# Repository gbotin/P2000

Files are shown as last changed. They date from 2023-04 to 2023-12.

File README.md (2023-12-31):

Infos :
Stepper : 28byj-48

http://suncalc.net/#/50.6244,2.6875,9/2023.12.01/15:34

FIFO readings
https://github.com/rlogiacco/CircularBuffer

https://github.com/adafruit/RTClib

### TODO :
- update stepper lib to accelstepper
- buy rtc module
- homing step motor - buy homing switch

### Utils :
- Read current time : echo "time_print" > /dev/tty.usbserial-1230
- Send current time : echo "time_set $(date +%s)" > /dev/tty.usbserial-1440
- Reset EEPROM : echo 'eeprom_reset' > /dev/tty.usbserial-1230

### Infos :
- Stepper : 28byj-48

### FIFO readings info
- https://github.com/rlogiacco/CircularBuffer

### Libs 

- https://github.com/PaulStoffregen/Time
- http://github.com/JChristensen/Timezone
- https://github.com/arduino-libraries/Stepper
- https://github.com/dmkishi/Dusk2Dawn

### Power Consumption

Mode SET idle : 0.0358V
Motor running 

sleep 0.146

max 0.2620

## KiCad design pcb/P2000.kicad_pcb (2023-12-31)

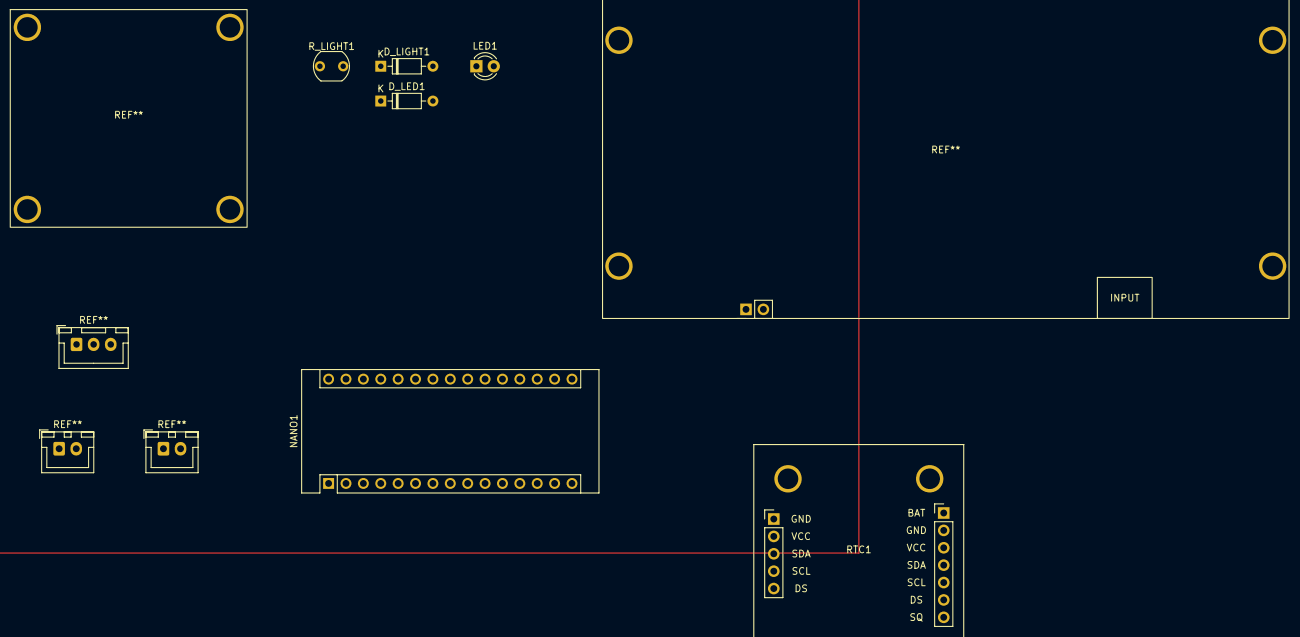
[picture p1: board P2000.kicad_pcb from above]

Board: 2 copper layers, 6 parts (0 on the bottom side), 8 nets, no tracks yet.

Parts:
D_LED1: 1N4148; D_DO-35_SOD27_P7.62mm_Horizontal
D_LIGHT1: 1N4148; D_DO-35_SOD27_P7.62mm_Horizontal
LED1: LED; LED_D3.0mm_Clear
NANO1: Arduino_Nano_v3.x; Arduino_Nano
RTC1: DS1307+; DS1307
R_LIGHT1: LDR07; R_LDR_5.1x4.3mm_P3.4mm_Vertical

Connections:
GND: LED1.1 (K), NANO1.4 (GND), RTC1.4 (GND)
unnamed: D_LED1.1 (K), LED1.2 (A)
unnamed: D_LED1.2 (A), NANO1.12 (D9)
unnamed: D_LIGHT1.1 (K), NANO1.19 (A0)
unnamed: D_LIGHT1.2 (A), R_LIGHT1.2
unnamed: NANO1.23 (A4), RTC1.5 (SDA)
unnamed: NANO1.24 (A5), RTC1.6 (SCL)
unnamed: NANO1.27 (+5V), RTC1.8 (VCC), R_LIGHT1.1

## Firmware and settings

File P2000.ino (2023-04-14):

#include <LowPower.h>

#include "src/defines.h"
#include "src/command.h"
#include "src/controls.h"
#include "src/door.h"
#include "src/eeprom.h"
#include "src/led.h"
#include "src/mode.h"
#include "src/time.h"

unsigned long lastwake;

void setup()
{
    Serial.begin(9600);

    pinMode(LED_PIN, OUTPUT);

    led_setState(LED_PIN, mode_is(Mode::Set));

    attachInterrupt(digitalPinToInterrupt(HOME_PIN), wake, RISING);
    attachInterrupt(digitalPinToInterrupt(RUN_PIN), wake, RISING);

    time_setup();
    ctrl_setup();
    door_setup(
        eeprom_getCurrPosition(),
        eeprom_getOpenPosition(),
        eeprom_getClosePosition());

    lastwake = millis();
}

void wake()
{
    static unsigned long last_interrupt_time = 0;
    unsigned long interrupt_time = millis();

    // debounce 200ms
    if (interrupt_time - last_interrupt_time > 200)
    {
        Serial.println("wake");
        lastwake = millis();
    }

    last_interrupt_time = interrupt_time;
}

void loop()
{
    ctrl_read();
    command_read();

    command_try("eeprom_reset", &command_eepromReset);
    command_try("time_set", &command_timeSet);
    command_try("date_set", &command_dateSet);
    command_try("scenario_for", &command_scenarioFor);

    if (ctrl_mode())
    {
        mode_toggle();
        led_setState(LED_PIN, mode_is(Mode::Set));
        delay(2000);
    }

    if (mode_is(Mode::Set))
    {
        if (ctrl_run())
        {
            door_toggle(ctrl_getDirection(), &eeprom_setCurrPosition);
            delay(2000);
        }

        if (ctrl_move())
        {
            door_move(ctrl_getDirection(), &ctrl_move, &ctrl_read, &eeprom_setCurrPosition);
            delay(2000);
        }

        if (ctrl_home())
        {
            door_set(ctrl_getDirection(), &eeprom_setDirectionPosition);
            led_blink(LED_PIN, 1);
            delay(2000);
        }
    }

    if (mode_is(Mode::Auto))
    {
        if (now() >= time_getActionTime(Action::Open, now()) && now() < time_getActionTime(Action::Close, now()))
        {
            door_toggle(Direction::Up, &eeprom_setCurrPosition);
        }

        if (now() >= time_getActionTime(Action::Close, now()) && now() > time_getActionTime(Action::Open, now()))
        {
            door_toggle(Direction::Down, &eeprom_setCurrPosition);
        }

        if (millis() >= lastwake + 10000) {
            door_powerDown();
            delay(1000);

            LowPower.powerDown(SLEEP_8S, ADC_OFF, BOD_OFF);
        }
    }

    delay(100);
}

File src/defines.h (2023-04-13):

#pragma once

#include <Arduino.h>

// LEDS
#define LED_PIN 9

// CONTROLS
#define DIRECTION_PIN 8
#define RUN_PIN 2
#define HOME_PIN 3

// LOCATION
#define LAT 50.62448840748527
#define LNG 2.6875116810701773
#define TMZ 1

// DOOR TIMING
#define S_DELTA_OPEN 0     // 0H
#define S_DELTA_CLOSE 3600 // 1H

#define S_MIN_OPEN 32400  // 1970-01-01 09:00:00 GMT+0
#define S_MIN_CLOSE 68400 // 1970-01-01 19:00:00 GMT+0

// STEPPER
#define STEPPER_PIN_1 4
#define STEPPER_PIN_2 5
#define STEPPER_PIN_3 6
#define STEPPER_PIN_4 7

// upwards max speed at half step + 300g = 840 grand MAX
// upwards max sans charge at half step 1700

#define MOTOR_SPEED 1000.0 // 1500.0
#define MOTOR_ACCEL 500.0

// EEPROM
#define POS_CURR_EEPROM_ADDR 0
#define POS_OPEN_EEPROM_ADDR 4
#define POS_CLOSE_EEPROM_ADDR 8

enum Direction
{
    Up,
    Down,
};

enum SunCycle
{
    Sunrise,
    Sunset,
};

enum Action
{
    Open,
    Close,
};

enum Mode
{
    Auto,
    Set,
};

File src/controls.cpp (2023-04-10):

#include "controls.h"

Button RunButton(RUN_PIN);
Button HomeButton(HOME_PIN);

// Home and Run buttons pressed for 1s
bool ctrl_mode()
{
    return RunButton.pressedFor(1000) && HomeButton.pressedFor(1000);
}

// Home button pressed for 1s and run button was not pressed last 0,5s
bool ctrl_home()
{
    return HomeButton.pressedFor(1000) && RunButton.releasedFor(500);
}

// Run button pressed for 1s and home button was not pressed last 0,5s
bool ctrl_move()
{
    return RunButton.pressedFor(1000) && HomeButton.releasedFor(500);
}

// Run button was pressed
bool ctrl_run()
{
    return RunButton.wasReleased();
}

void ctrl_read()
{
    HomeButton.read();
    RunButton.read();
}

void ctrl_setup()
{
    pinMode(RUN_PIN, INPUT_PULLUP);
    pinMode(HOME_PIN, INPUT_PULLUP);
    pinMode(DIRECTION_PIN, INPUT);

    HomeButton.begin();
    RunButton.begin();
}

bool ctrl_isDirectionUp()
{
    return !digitalRead(DIRECTION_PIN);
}

bool ctrl_isDirectionDown()
{
    return digitalRead(DIRECTION_PIN);
}

Direction ctrl_getDirection()
{
    return ctrl_isDirectionUp() ? Direction::Up : Direction::Down;
}

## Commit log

2021-05-24 Buttons control OK
2023-03-18 Tests after motor perf problems
    [P2000.ino, door.cpp]
2023-04-10 Add state control to led
2023-04-14 Fix motor power consumption
    [P2000.ino, door.cpp]
2023-12-31 Start planning PCB
    [P2000.fzz, P2000.kicad_pcb, P2000.kicad_sch]
